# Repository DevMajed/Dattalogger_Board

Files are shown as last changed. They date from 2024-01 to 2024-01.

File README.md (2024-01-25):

# MCU Datalogger with memory and clock

## Project Overview: 
**Project Name:**  
MCU Data Logger for ATmega328-AU  
Author: Majed Alharbi [ Majed Dev ]  
URL: https://github.com/DevMajed/Dattalogger_Board.git  

<br>  

07FD53B6-CE86-47E1-A673-1FB48E3DFB10 

<br>  

**Objective :**  
The MCU Data Logger is designed to log data from various sensors or peripherals connected to an ATmega328-AU microcontroller.  
The project incorporates features such as external EEPROM memory (24LC1025), a real-time clock (DS1337S), and essential connectors for communication and programming.

## Block Diagram / Circuit Schematic :

Schematic

**ATmega328-AU:**  
Main microcontroller responsible for data processing, sensor interfacing, and overall control of the system.

**EEPROM (24LC1025):**  
External EEPROM memory for storing data logs, and it rovides non-volatile extended storage capacity.

**Real-Time Clock (DS1337S):**  
Provides accurate timekeeping for timestamping data logs.

**Real time Crystal Oscillator:**  
32.768 kHz: Connected to DS1337S for precise real-time tracking.

**High speed Crystal Oscillator :**  
16 MHz, Connected to Pins B6 and B7 of the AVR, with capacitors for stable clock operation.

**Connectors:**  
UART: For serial communication.  
ICSP: In-Circuit Serial Programming for firmware updates.  
I2C: General-purpose I2C communication.  
GPIO: General-purpose input/output for additional peripherals.  

**Interactions between Blocks:**  
* The ATmega328-AU communicates with the EEPROM over the I2C bus, storing and retrieving data logs.  
* The DS1337S sends real-time information to the ATmega328-AU, allowing accurate timestamping of data.  
* The 16 MHz crystal oscillator provides the main clock signal for the ATmega328-AU, ensuring proper execution of instructions.  
* Connectors facilitate external communication and programming, enhancing the project's versatility.  

## Specifications:  
Microcontroller: ATmega328-AU  
EEPROM: 24LC1025  
Real-Time Clock: DS1337S  
Crystal Oscillators:  
32.768 kHz (for DS1337S)  
16 MHz (for ATmega328-AU)  
Connectors: UART, ICSP, I2C, GPIO  
Power Supply: 5V battery "MCU 1.8V to 5.5V, EEPROM and DS1337S 2.3V to 5.5V. Oscillators 5V."  
Communication Protocols: I2C, UART  
Programming Language: C/C++  

## PCB Specifications:  
**Sginals Track width :**  
0.25 mm  
**VCC/GND Track width :**   
0.35 mm  
**Signal Layers:**   
Top F.Cu + Ln2.Cu    
**Power Layer  :**  
Ln1.Cu with Copper fills  
**Ground Layer :**  
Bottom B.Cu with Copper fills

## BOM : Bill of materials

  

# Contact Info
## If you have any questions email me : dev.majed.alharbi@gmail.com

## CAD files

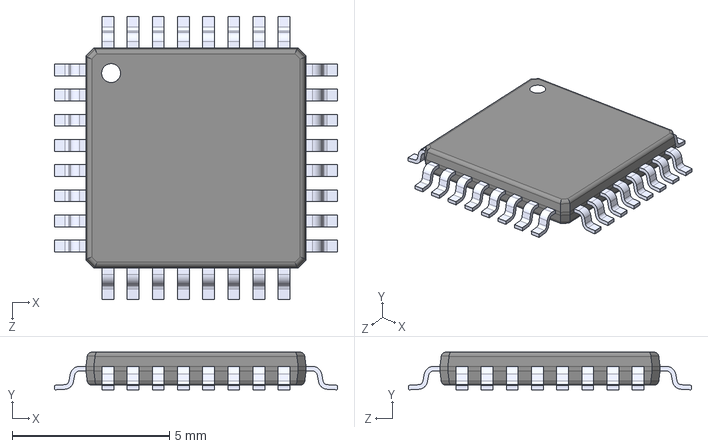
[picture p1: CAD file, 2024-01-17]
Project_Libraries/ATMEGA328P-AU/ATMEGA328P-AU.step
9.00 x 1.20 x 9.00 mm

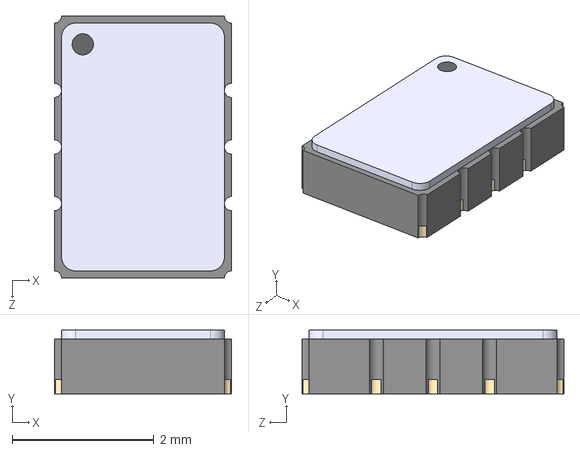
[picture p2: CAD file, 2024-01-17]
Project_Libraries/RV-3129-C3/RV-3129-C3.step
2.50 x 0.9 x 3.70 mm

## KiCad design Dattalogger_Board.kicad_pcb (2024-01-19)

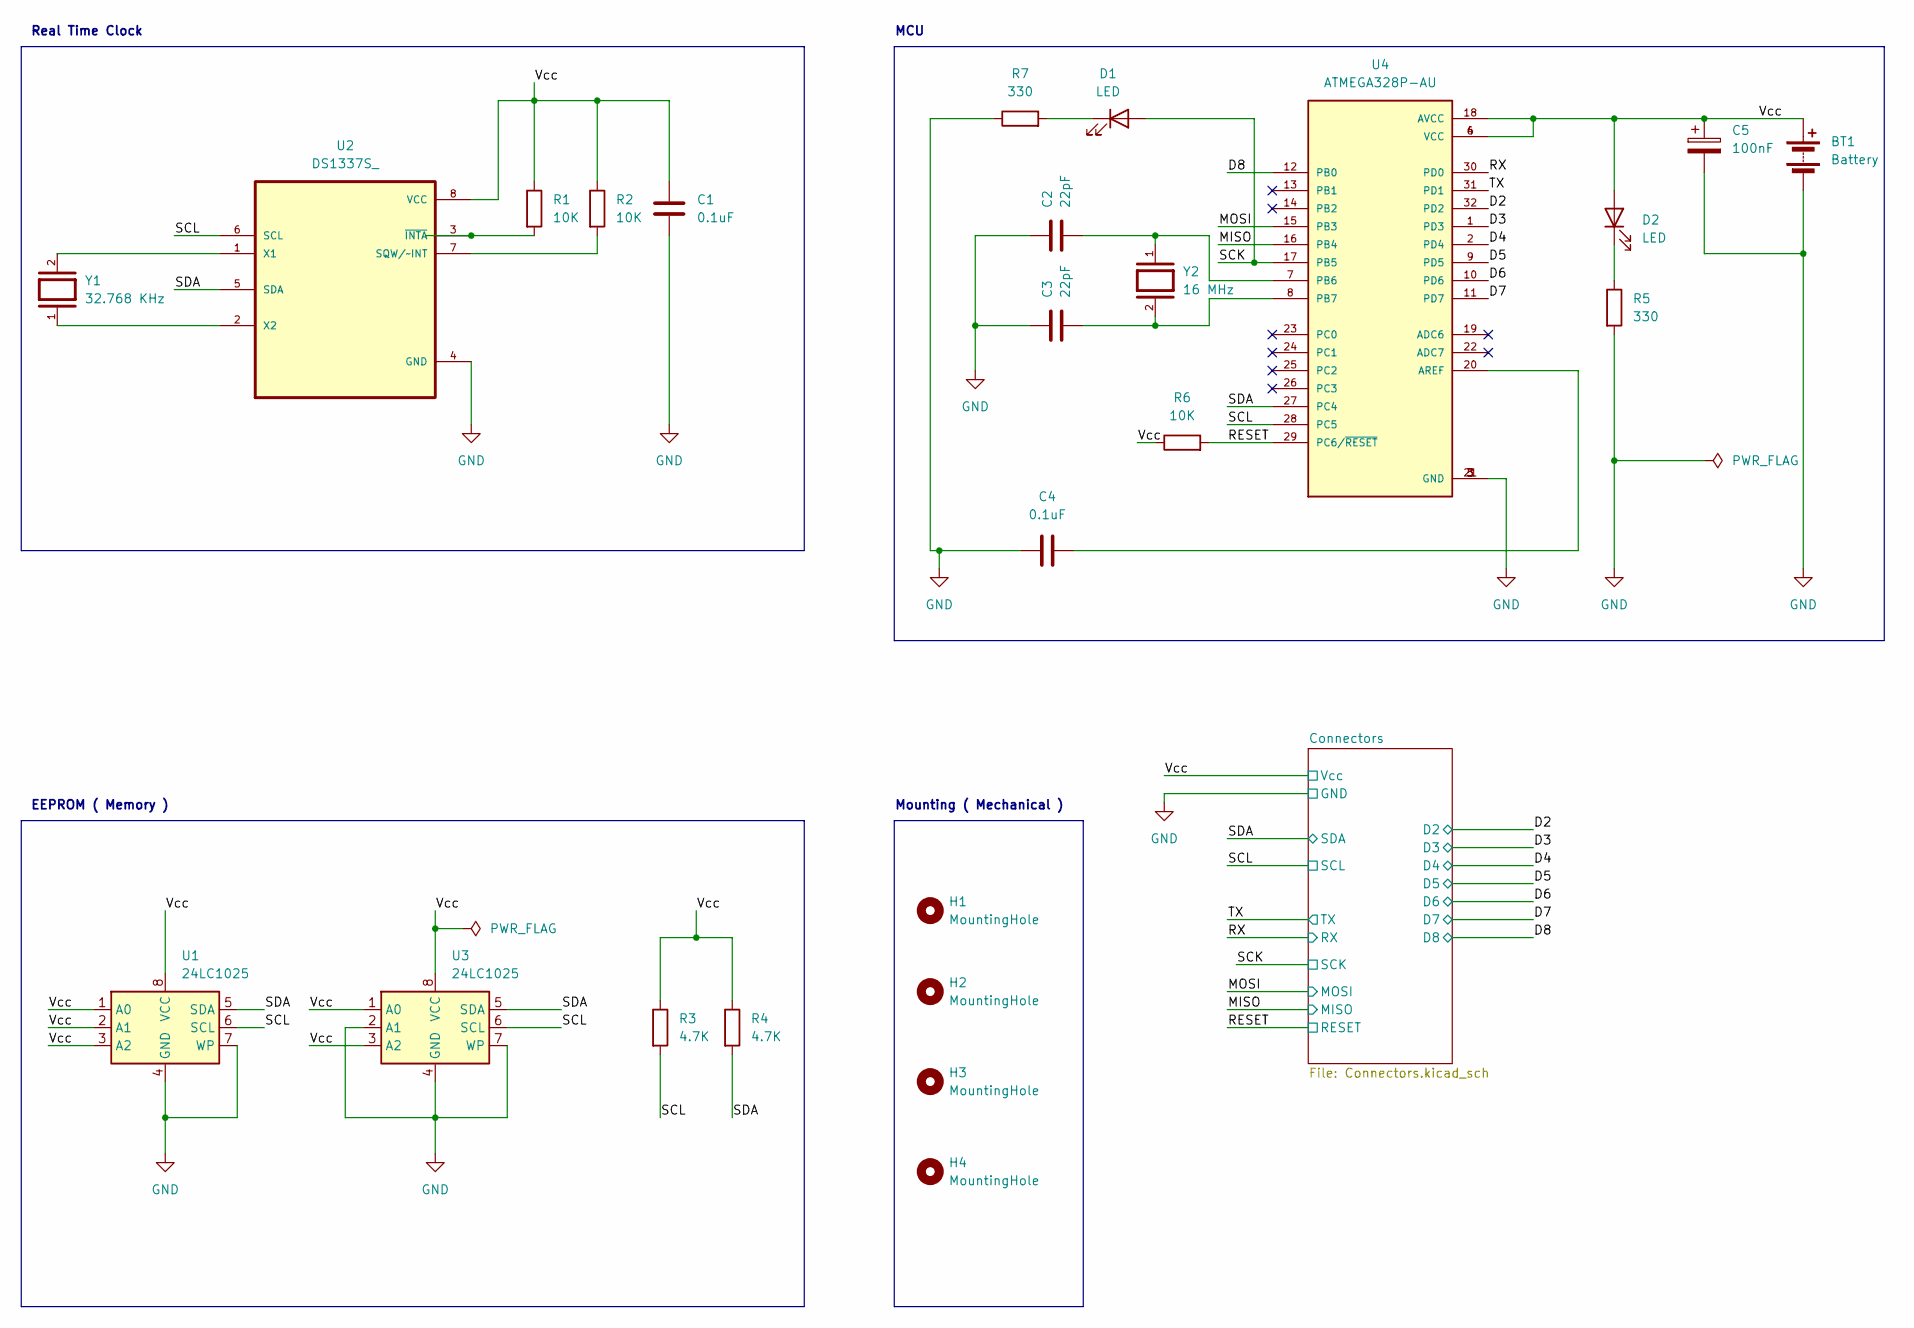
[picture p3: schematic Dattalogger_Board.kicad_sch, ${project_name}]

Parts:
BT1: Battery; PinHeader_2x01_P2.54mm_Vertical
C1, C4: 0.1uF; C_0805_2012Metric
C2, C3: 22pF; C_0805_2012Metric
C5: 100nF; C_0805_2012Metric
D1, D2: LED; LED_0805_2012Metric
H1, H2, H3, H4: MountingHole; MountingHole_2.1mm
R1, R2, R6: 10K; R_0805_2012Metric
R3, R4: 4.7K; R_0805_2012Metric
R5, R7: 330; R_0805_2012Metric
U1, U3: 24LC1025; SOIC-8_5.23x5.23mm_P1.27mm
U2: DS1337S_; SOIC127P600X175-8N
U4: ATMEGA328P-AU; QFP80P900X900X120-32N; PARTREV 8271A
Y1: 32.768 KHz; Crystal_SMD_5032-2Pin_5.0x3.2mm_HandSoldering; PARTREV 8.1/03.2021
Y2: 16 MHz; Crystal_SMD_5032-2Pin_5.0x3.2mm_HandSoldering; PARTREV 8.1/03.2021

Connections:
/D2: U4.32 (PD2); also elsewhere on the board
/D3: U4.1 (PD3); also elsewhere on the board
/D4: U4.2 (PD4); also elsewhere on the board
/D5: U4.9 (PD5); also elsewhere on the board
/D6: U4.10 (PD6); also elsewhere on the board
/D7: U4.11 (PD7); also elsewhere on the board
/D8: U4.12 (PB0); also elsewhere on the board
/MISO: U4.16 (PB4); also elsewhere on the board
/MOSI: U4.15 (PB3); also elsewhere on the board
/RESET: R6.2, U4.29 (PC6/~RESET); also elsewhere on the board
/RX: U4.30 (PD0); also elsewhere on the board
/SCK: D1.2 (A), R3.2, U1.6 (SCL), U2.6 (SCL), U3.6 (SCL), U4.17 (PB5), U4.28 (PC5); also elsewhere on the board
/SDA: R4.2, U1.5 (SDA), U2.5 (SDA), U3.5 (SDA), U4.27 (PC4); also elsewhere on the board
/TX: U4.31 (PD1); also elsewhere on the board
/Vcc: BT1.1 (+), C1.1, C5.1, D2.2 (A), R1.1, R2.1, R3.1, R4.1, R6.1, U1.1 (A0), U1.2 (A1), U1.3 (A2), U1.8 (VCC), U2.8 (VCC), U3.1 (A0), U3.3 (A2), U3.8 (VCC), U4.4 (VCC), U4.6 (VCC), U4.18 (AVCC); also elsewhere on the board
GND: BT1.2 (-), C1.2, C2.1, C3.1, C4.1, C5.2, R5.2, R7.1, U1.4 (GND), U1.7 (WP), U2.4 (GND), U3.2 (A1), U3.4 (GND), U3.7 (WP), U4.3 (GND), U4.5 (GND), U4.21 (GND); also elsewhere on the board
unnamed: D1.1 (K), R7.2
unnamed: D2.1 (K), R5.1
unnamed: R2.2, U2.7 (SQW/~INT)
unnamed: U2.1 (X1), Y1.2
unnamed: U2.2 (X2), Y1.1
unnamed: R1.2, U2.3 (~INTA)
unnamed: C4.2, U4.20 (AREF)
unnamed: C2.2, U4.7 (PB6), Y2.1
unnamed: C3.2, U4.8 (PB7), Y2.2

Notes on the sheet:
MCU
EEPROM ( Memory )
Mounting ( Mechanical )
Real Time Clock

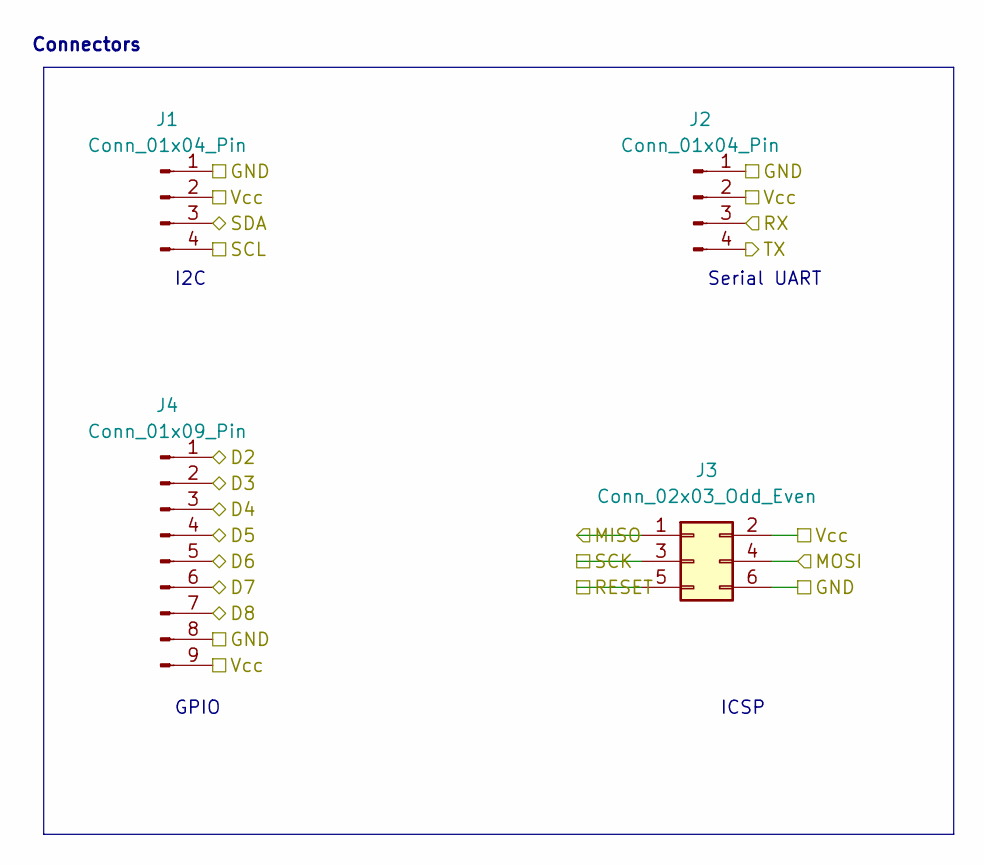
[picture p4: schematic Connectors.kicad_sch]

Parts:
J1, J2: Conn_01x04_Pin; PinHeader_1x04_P2.54mm_Vertical
J3: Conn_02x03_Odd_Even; PinHeader_2x03_P2.54mm_Vertical
J4: Conn_01x09_Pin; PinHeader_1x09_P2.54mm_Vertical

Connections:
/D2: J4.1; also elsewhere on the board
/D3: J4.2; also elsewhere on the board
/D4: J4.3; also elsewhere on the board
/D5: J4.4; also elsewhere on the board
/D6: J4.5; also elsewhere on the board
/D7: J4.6; also elsewhere on the board
/D8: J4.7; also elsewhere on the board
/MISO: J3.1; also elsewhere on the board
/MOSI: J3.4; also elsewhere on the board
/RESET: J3.5; also elsewhere on the board
/RX: J2.3; also elsewhere on the board
/SCK: J1.4, J3.3; also elsewhere on the board
/SDA: J1.3; also elsewhere on the board
/TX: J2.4; also elsewhere on the board
/Vcc: J1.2, J2.2, J3.2, J4.9; also elsewhere on the board
GND: J1.1, J2.1, J3.6, J4.8; also elsewhere on the board

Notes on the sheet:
Connectors
ICSP
GPIO
Serial UART
I2C

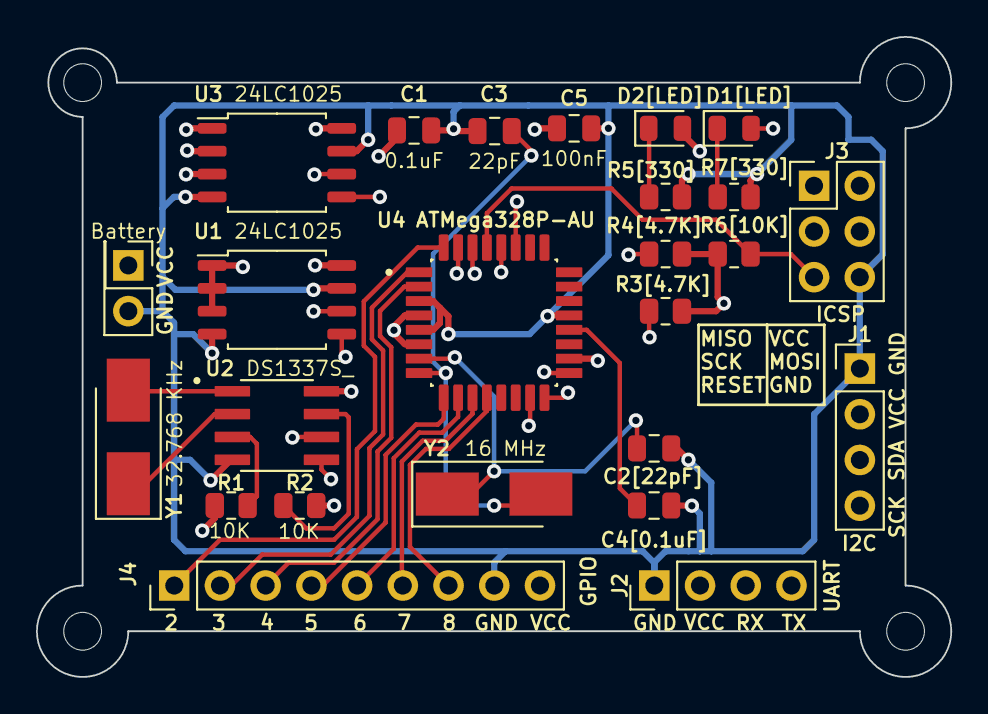
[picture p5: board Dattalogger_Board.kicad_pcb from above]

Board: 4 copper layers, 50.8 x 35.6 mm, 30 parts (1 on the bottom side), 25 nets.

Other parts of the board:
Majed: LOGO; MajedDev

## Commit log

2024-01-16 First commit of new project.
    [Dattalogger_Board.kicad_pcb, Dattalogger_Board.kicad_sch]
2024-01-16 preparing new project
    [Dattalogger_Board.kicad_sch]
2024-01-17 Have added required symbols to the schematic sheets.
    [ATMEGA328P-AU.step, Connectors.kicad_sch, Dattalogger_Board.kicad_sch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]
2024-01-17 Changed Locations of Symbols (arrange).
    [Connectors.kicad_sch, Dattalogger_Board.kicad_sch]
2024-01-17 Added Components Values
    [Connectors.kicad_sch, Dattalogger_Board.kicad_sch]
2024-01-17 Completed Symbol-Footprint associations.
    [Connectors.kicad_sch]
2024-01-17 More footprint assignment
    [Connectors.kicad_sch, Dattalogger_Board.kicad_sch]
2024-01-17 The wiring for the root sheet is complete.
    [Connectors.kicad_sch, Dattalogger_Board.kicad_pcb, Dattalogger_Board.kicad_sch]
2024-01-17 Allocated GND and Vcc Nets to the power net class
    [Connectors.kicad_sch, Dattalogger_Board.kicad_sch]
2024-01-17 Addoed Power Flag and finished ERC
    [Dattalogger_Board.kicad_sch]
2024-01-17 Completed comments
    [Connectors.kicad_sch, Dattalogger_Board.kicad_sch]
2024-01-17 Orgnizing schematic and making new branch
    [Dattalogger_Board.kicad_sch]
2024-01-17 finishing schematic
2024-01-17 Setting up layout Pcbnew
    [Dattalogger_Board.kicad_pcb, Dattalogger_Board.kicad_sch]
2024-01-17 Completed Placments of footprints and sizing the board
    [Dattalogger_Board.kicad_pcb]
2024-01-17 Completed footprint placments and board sizing
2024-01-17 Refined and completed outline
    [Dattalogger_Board.kicad_pcb]
2024-01-18 Completed Routing
    [Dattalogger_Board.kicad_pcb]
2024-01-18 Completed the 2-layer board
    [Dattalogger_Board-B_Cu.gbl, Dattalogger_Board-B_Mask.gbs, Dattalogger_Board-B_Paste.gbp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]
2024-01-19 Completed 2-Layer PCB
    [Dattalogger_Board-B_Cu.gbl, Dattalogger_Board-B_Mask.gbs, Dattalogger_Board-B_Paste.gbp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]
2024-01-19 Committing local changes before merge
    [Dattalogger_Board-B_Cu.gbl, Dattalogger_Board-B_Mask.gbs, Dattalogger_Board-B_Paste.gbp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]
2024-01-19 Completed 2 Layer PCB
2024-01-19 Completed the 2 Layer PCB
    [Dattalogger_Board.kicad_pcb, Dattalogger_Board.kicad_sch]
2024-01-19 Completed 3-layer pcb routing
    [Dattalogger_Board.kicad_pcb]
2024-01-19 fixed bugs in schematic
    [Connectors.kicad_sch, Dattalogger_Board.kicad_sch]
2024-01-19 Fixing Bugs & merging projects in one folder
    [Dattalogger_Board-B_Cu.gbl, Dattalogger_Board-B_Mask.gbs, Dattalogger_Board-B_Paste.gbp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]
